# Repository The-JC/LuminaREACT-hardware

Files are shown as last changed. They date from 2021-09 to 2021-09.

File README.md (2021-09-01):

# LuminaREACT - Hardware
This repository is the hardware documentation of the LuminaREACT project.

LuminaREACT is CORTEX-M4 based audio visualizer for LED strips using the WS2812 led chip.
For further information visit: [LuminaREACT Firmware](https://lab.katurisoft.com/katurisoft/luminareact/firmware)

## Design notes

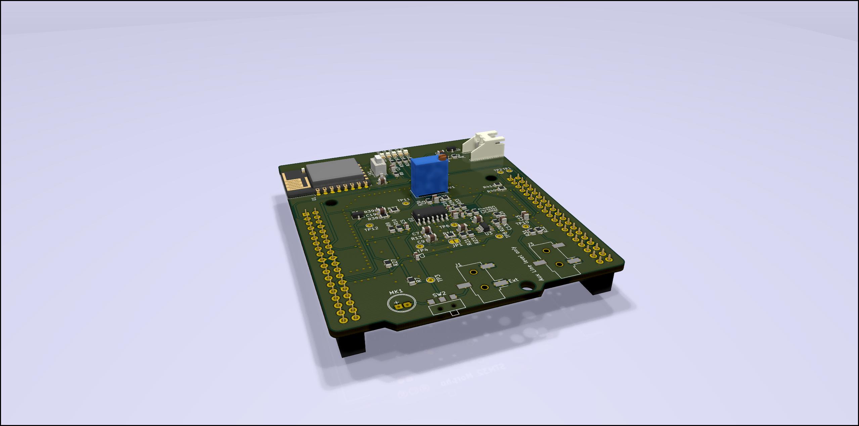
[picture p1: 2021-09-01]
LuminaREACT_hat/LuminaREACT_hat.jpg

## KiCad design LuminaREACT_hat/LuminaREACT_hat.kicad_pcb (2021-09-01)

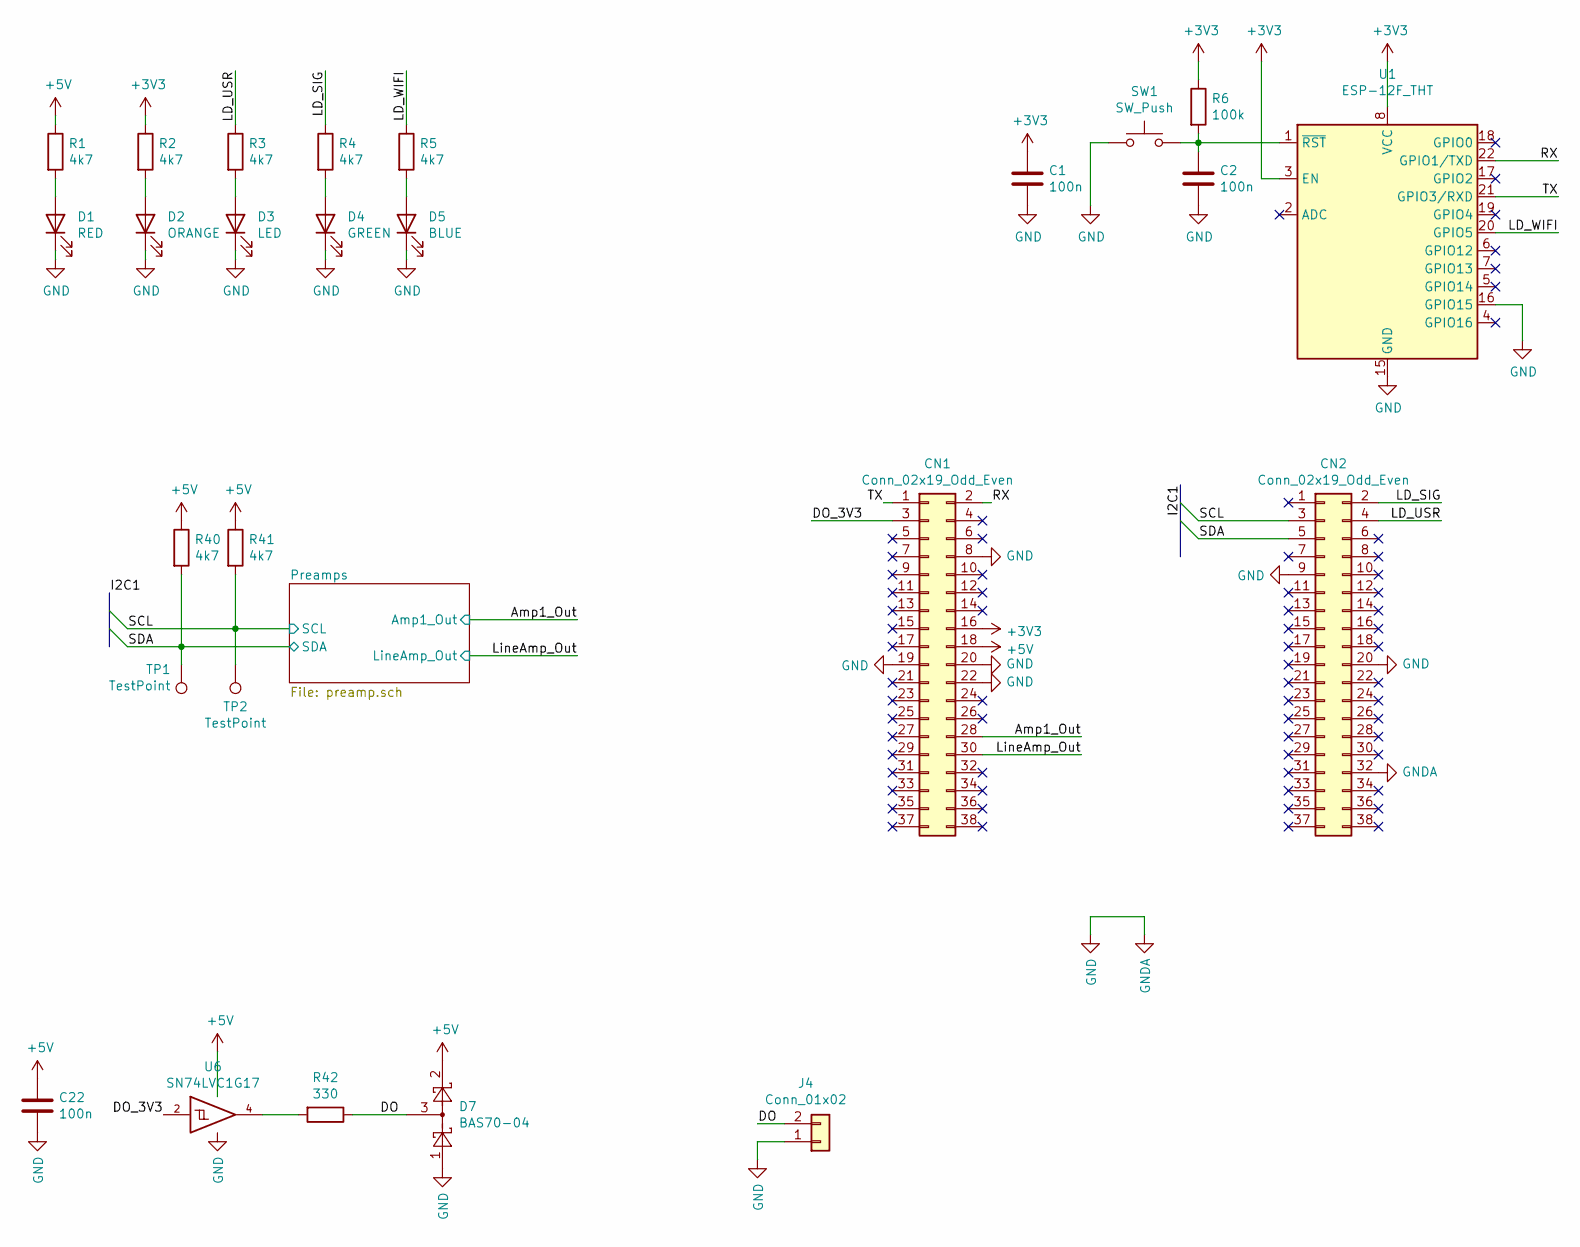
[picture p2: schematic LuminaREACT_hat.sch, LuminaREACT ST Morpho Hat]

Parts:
C1, C2, C22: 100n; C_0805_2012Metric
CN1, CN2: Conn_02x19_Odd_Even; PinSocket_2x19_P2.54mm_Vertical
D1: RED; LED_0805_2012Metric
D2: ORANGE; LED_0805_2012Metric
D3: LED; LED_0805_2012Metric
D4: GREEN; LED_0805_2012Metric
D5: BLUE; LED_0805_2012Metric
D7: BAS70-04; SOT-23; LCSC C150242
J4: Conn_01x02; JST_XH_S2B-XH-A-1_1x02_P2.50mm_Horizontal
R1, R2, R3, R4, R5, R40, R41: 4k7; R_0805_2012Metric
R6: 100k; R_0805_2012Metric
R42: 330; R_0805_2012Metric
SW1: SW_Push; SW_SPST_1TS002
TP1, TP2: TestPoint; TestPoint_THTPad_D1.5mm_Drill0.7mm
U1: ESP-12F_THT; ESP-12E-THT
U6: SN74LVC1G17; SOT-23-5_HandSoldering; LCSC C7836

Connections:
+3V3: C1.1, CN1.16, R2.1, R6.1, U1.3 (EN), U1.8 (VCC); also elsewhere on the board
/Amp1_Out: CN1.28; also elsewhere on the board
/DO: D7.3, J4.2, R42.1
/DO_3V3: CN1.3, U6.2
/LD_SIG: CN2.2, R4.1
/LD_USR: CN2.4, R3.1
/LD_WIFI: R5.1, U1.20 (GPIO5)
/LineAmp_Out: CN1.30; also elsewhere on the board
/RX: CN1.2, U1.22 (GPIO1/TXD)
/SCL: CN2.3, R41.2, TP2.1; also elsewhere on the board
/SDA: CN2.5, R40.2, TP1.1; also elsewhere on the board
/TX: CN1.1, U1.21 (GPIO3/RXD)
GND: C1.2, C2.2, C22.2, CN1.8, CN1.19, CN1.20, CN1.22, CN2.9, CN2.20, CN2.32, D1.1 (K), D2.1 (K), D3.1 (K), D4.1 (K), D5.1 (K), D7.1, J4.1, SW1.1, U1.15 (GND), U1.16 (GPIO15), U6.3 (GND); also elsewhere on the board
unnamed: C2.1, R6.2, SW1.2, U1.1 (~RST)
unnamed: D1.2 (A), R1.2
unnamed: D2.2 (A), R2.2
unnamed: D3.2 (A), R3.2
unnamed: D4.2 (A), R4.2
unnamed: D5.2 (A), R5.2
unnamed: R42.2, U6.4

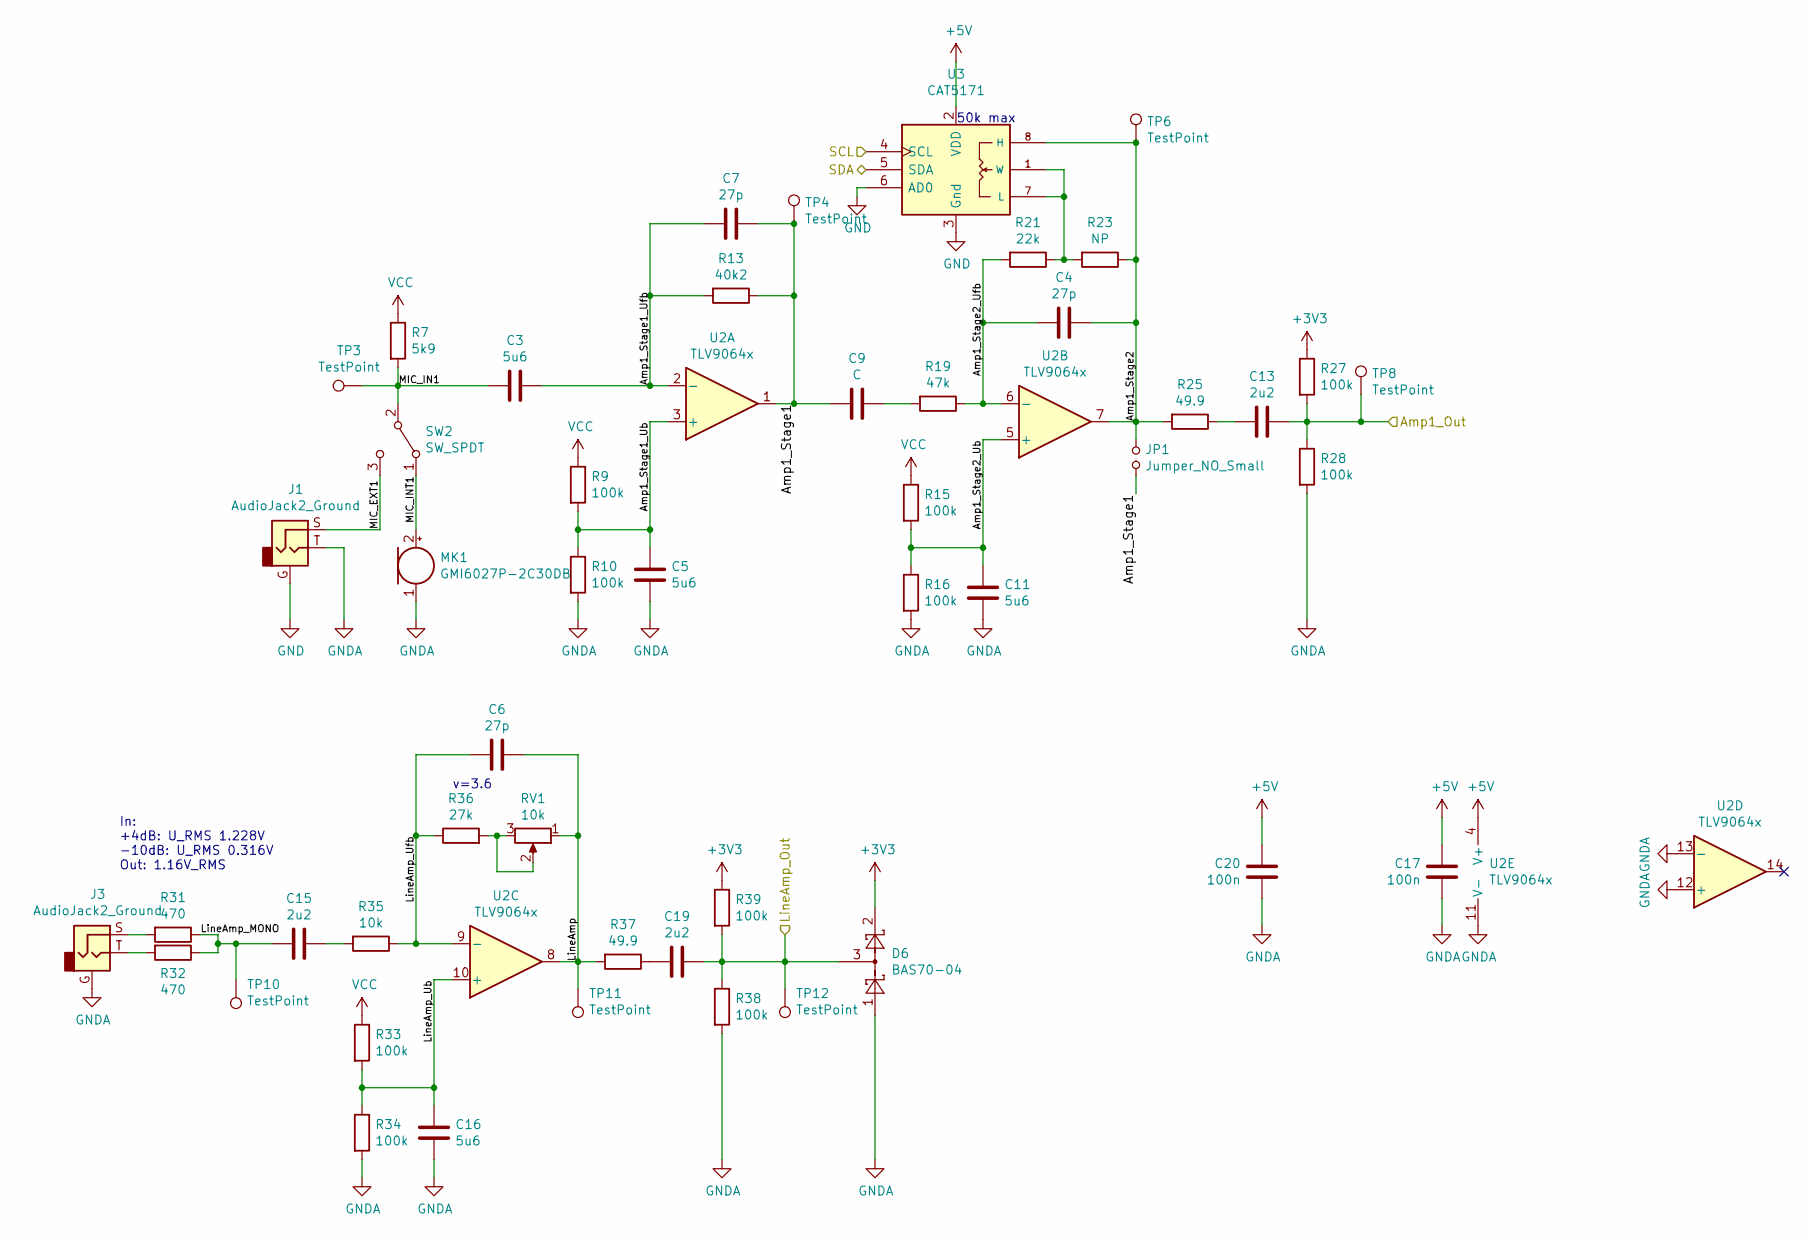
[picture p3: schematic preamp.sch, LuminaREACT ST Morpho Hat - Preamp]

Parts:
C3, C5, C11, C16: 5u6; C_0603_1608Metric_Pad1.05x0.95mm_HandSolder
C4, C6, C7: 27p; C_0805_2012Metric
C9: C; C_0805_2012Metric
C13, C15, C19: 2u2; C_0805_2012Metric
C17, C20: 100n; C_0805_2012Metric
D6: BAS70-04; SOT-23; LCSC C150242
J1, J3: AudioJack2_Ground; Jack_3.5mm_BOOMELE_PJ-320B-SMT_Horizontal
JP1: Jumper_NO_Small; SolderJumper-2_P1.3mm_Open_RoundedPad1.0x1.5mm
MK1: GMI6027P-2C30DB; MIC_6.0x2.7MM; LCSC C233898
R7: 5k9; R_0805_2012Metric
R9, R10, R15, R16, R27, R28, R33, R34, R38, R39: 100k; R_0805_2012Metric
R13: 40k2; R_0805_2012Metric
R19: 47k; R_0805_2012Metric
R21: 22k; R_0805_2012Metric
R23: NP; R_0805_2012Metric
R25, R37: 49.9; R_0805_2012Metric
R31, R32: 470; R_0805_2012Metric
R35: 10k; R_0805_2012Metric
R36: 27k; R_0805_2012Metric
RV1: 10k; Potentiometer_Bourns_3296W_Vertical
SW2: SW_SPDT; SW_SPDT_SK-3390
TP3, TP4, TP6, TP8, TP10, TP11, TP12: TestPoint; TestPoint_THTPad_D1.5mm_Drill0.7mm
U2: TLV9064x; SO-14_3.9x8.65mm_P1.27mm; LCSC C388176
U3: CAT5171; SOT-23-8_Handsoldering; LCSC C154777

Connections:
+3V3: D6.2, R27.1, R39.1; also elsewhere on the board
/Amp1_Out: C13.1, R27.2, R28.1, TP8.1; also elsewhere on the board
/LineAmp_Out: C19.1, D6.3, R38.1, R39.2, TP12.1; also elsewhere on the board
/Preamps/Amp1_Stage1: C7.1, C9.2, JP1.1, R13.1, TP4.1, U2.1
/Preamps/Amp1_Stage1_Ub: C5.1, R9.2, R10.1, U2.3 (+)
/Preamps/Amp1_Stage1_Ufb: C3.1, C7.2, R13.2, U2.2 (-)
/Preamps/Amp1_Stage2: C4.1, JP1.2, R23.1, R25.2, TP6.1, U2.7, U3.8 (H)
/Preamps/Amp1_Stage2_Ub: C11.1, R15.2, R16.1, U2.5 (+)
/Preamps/Amp1_Stage2_Ufb: C4.2, R19.1, R21.2, U2.6 (-)
/Preamps/LineAmp: C6.1, R37.2, RV1.1, TP11.1, U2.8
/Preamps/LineAmp_MONO: C15.2, R31.1, R32.1, TP10.1
/Preamps/LineAmp_Ub: C16.1, R33.2, R34.1, U2.10 (+)
/Preamps/LineAmp_Ufb: C6.2, R35.1, R36.1, U2.9 (-)
/Preamps/MIC_EXT1: J1.S, SW2.3 (C)
/Preamps/MIC_IN1: C3.2, R7.2, SW2.2 (B), TP3.1
/Preamps/MIC_INT1: MK1.2 (+), SW2.1 (A)
/SCL: U3.4 (SCL); also elsewhere on the board
/SDA: U3.5 (SDA); also elsewhere on the board
GND: C5.2, C11.2, C16.2, C17.2, C20.2, D6.1, J1.G, J1.T, J3.G, MK1.1 (-), R10.2, R16.2, R28.2, R34.2, R38.2, U2.11 (V-), U2.12 (+), U2.13 (-), U3.3 (Gnd), U3.6 (AD0); also elsewhere on the board
unnamed: C9.1, R19.2
unnamed: C13.2, R25.1
unnamed: C15.1, R35.2
unnamed: C19.2, R37.1
unnamed: J3.S, R31.2
unnamed: J3.T, R32.2
unnamed: R21.1, R23.2, U3.1 (W), U3.7 (L)
unnamed: R36.2, RV1.2, RV1.3

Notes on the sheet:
50k max
v=3.6
In: +4dB: U_RMS 1.228V -10dB: U_RMS 0.316V Out: 1.16V_RMS

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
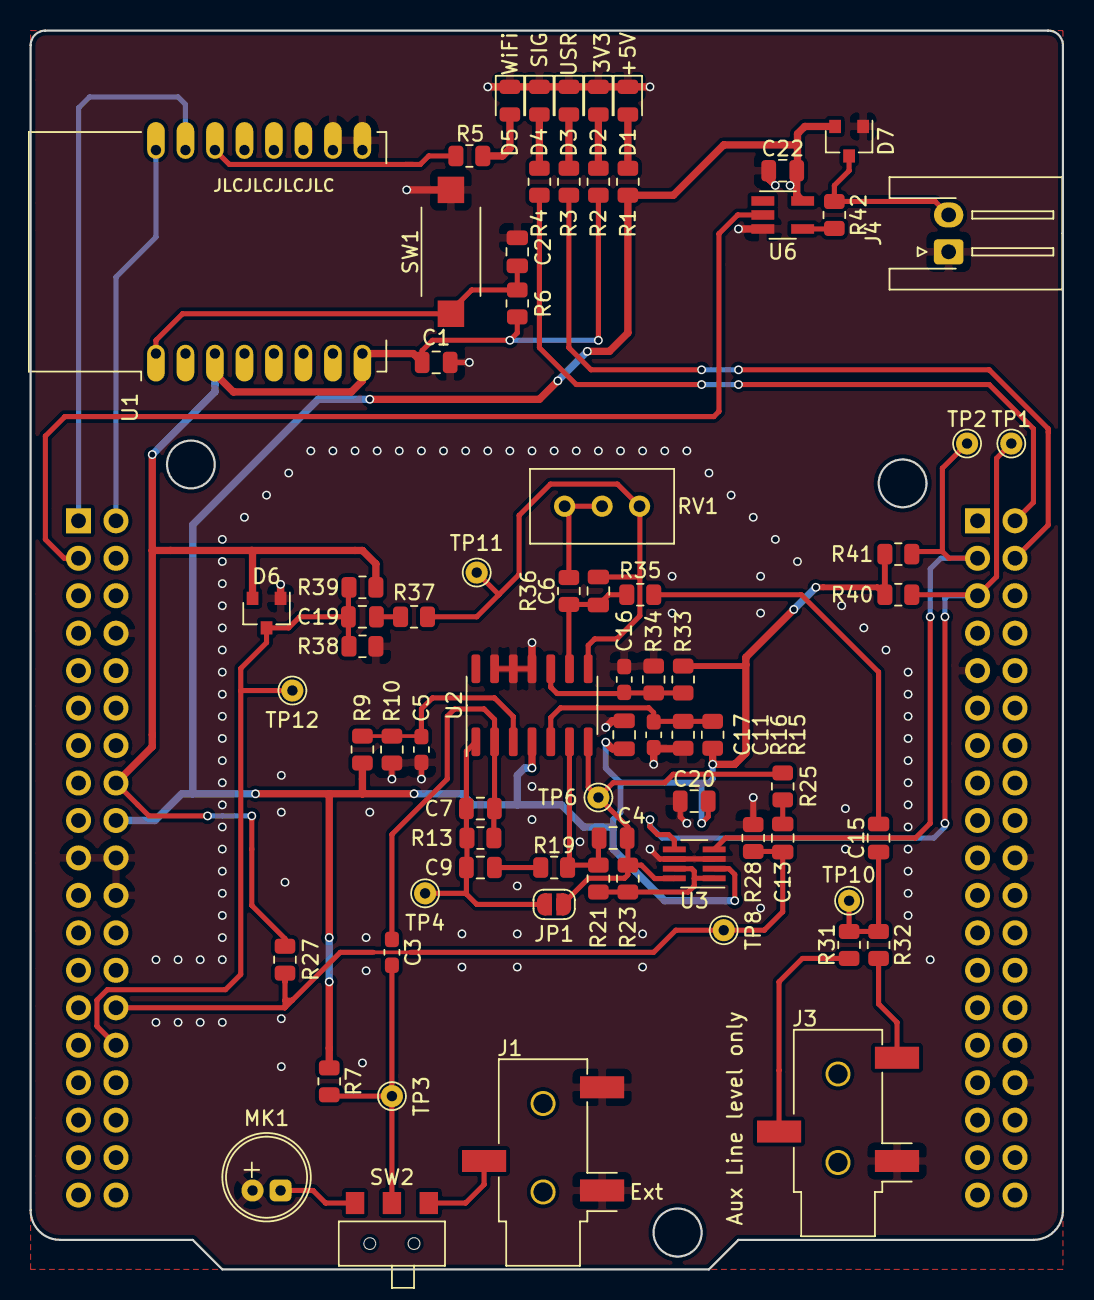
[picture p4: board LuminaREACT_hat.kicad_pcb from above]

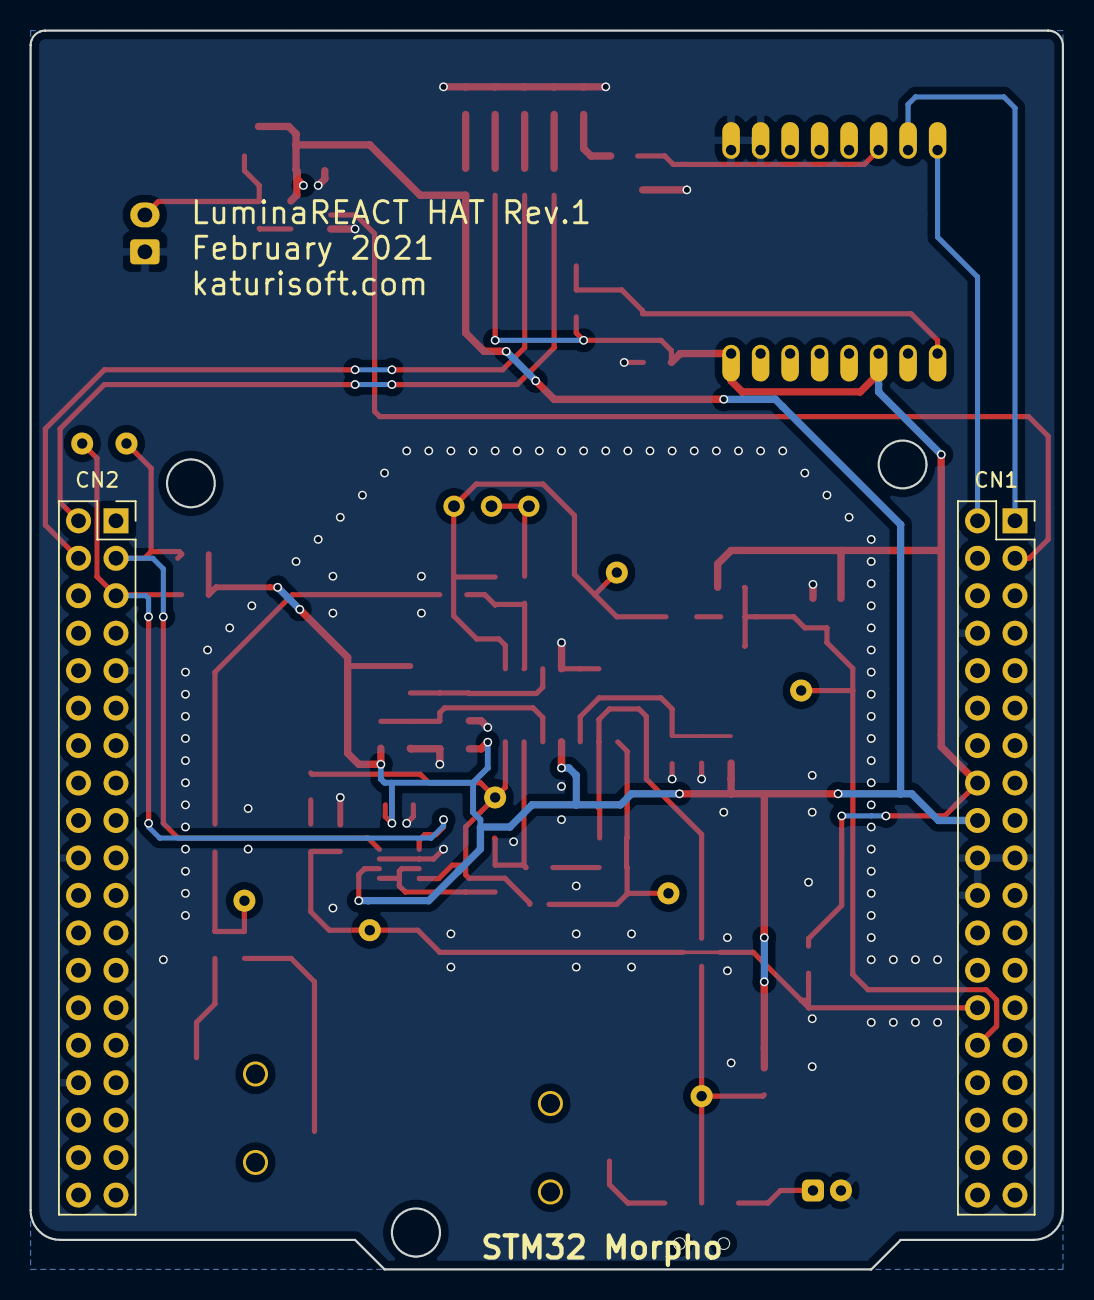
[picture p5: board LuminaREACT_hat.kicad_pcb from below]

Board: 2 copper layers, 70.0 x 84.0 mm, 76 parts (2 on the bottom side), 42 nets.
